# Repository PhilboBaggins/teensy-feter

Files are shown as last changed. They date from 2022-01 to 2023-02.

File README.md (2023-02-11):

# Teensy FETer

A small board with 10 power outputs driven from FETs configured as high side switches and controlled by a Teensy LC. This board was mainly created for experimenting with solenoids.

| Photo of board using external power |  Photo of board using USB power |
| --- |  --- |
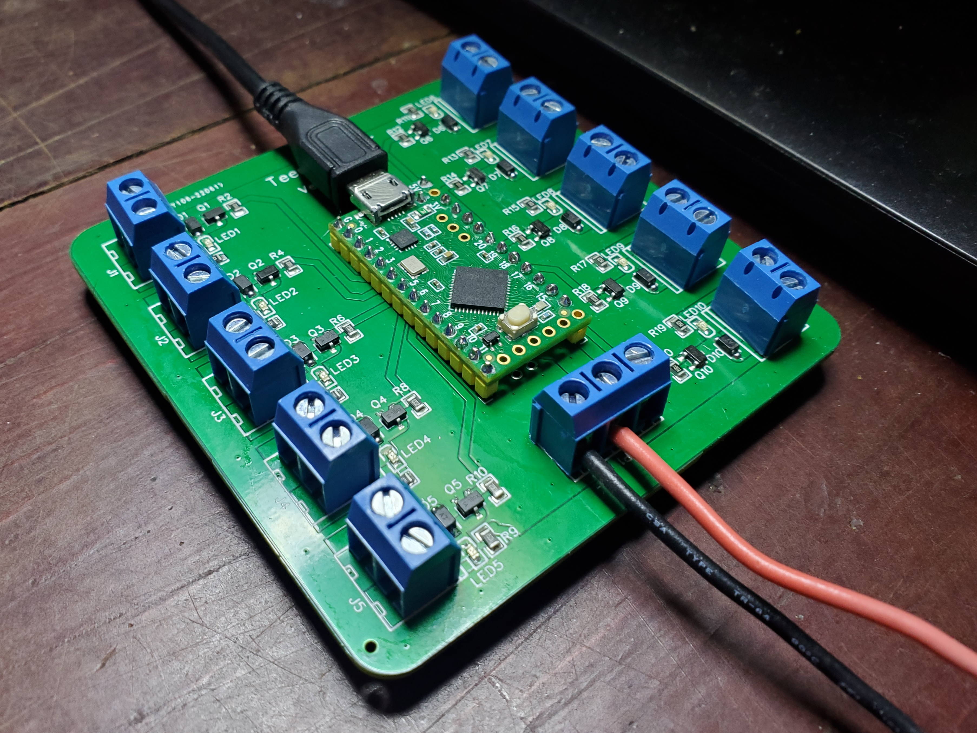
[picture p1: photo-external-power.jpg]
Photo of board using external power
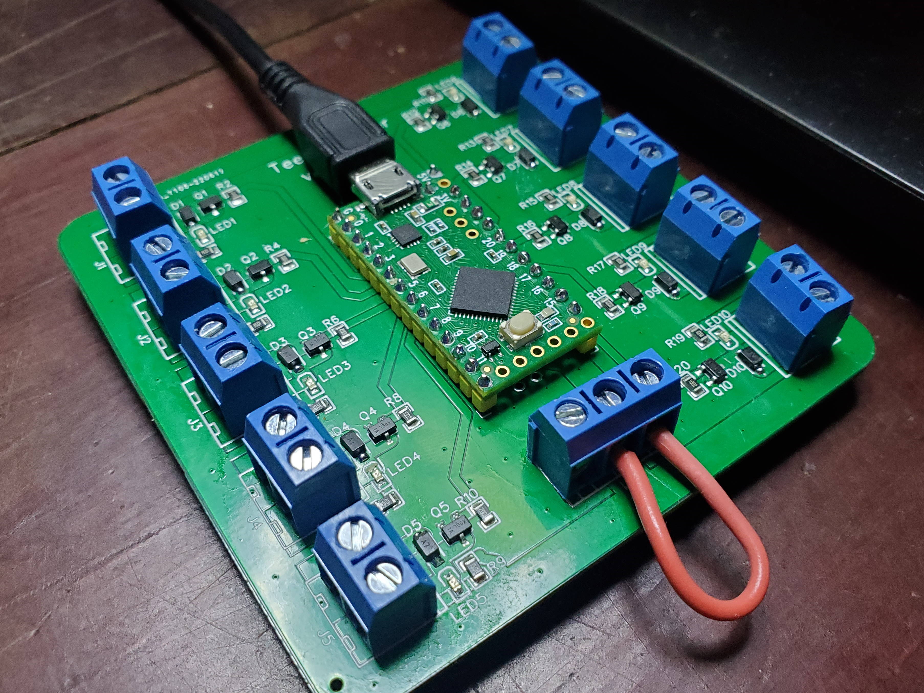
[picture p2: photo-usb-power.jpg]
Photo of board using USB power
|  |  |

## Output pins

Each of the 10 outputs is controlled by a single Teensy pin:

| Output | Teensy pin |
| --- | --- |
| OUT1 | 2 |
| OUT2 | 3 |
| OUT3 | 4 |
| OUT4 | 5 |
| OUT5 | 6 |
| OUT6 | 23 |
| OUT7 | 22 |
| OUT8 | 21 |
| OUT9 | 20 |
| OUT10  | 19 |

## Usage notes

The "external power" pin (centre of the 3 pin screw terminal) is connected to the first pin of each of the output connectors (2 pin screw terminals). These aren't clearly labelled on the v1.0 boards, so if you're unsure look at the bottom of the board and follow the thick copper trace going around the outside of the board.

Whatever power is connected to the "external power" pin will supply power to whatever load you've connected to the output connectors (e.g. a solenoid). The LEDs on the board are also driven from the "external power".

There are two principle ways of using this board, which are shown in the photos above and described in more detail in the paragraphs below.

### Configuration 1 - External power supply

This board can be powered from an external power by connecting it pins 1 and 2 of the 3 pin screw terminal as shown in the photo above (the one on the left). Ground from the external supply should be connected to pin 1 and power to pin 2.

In this configuration the external power supply is connected to the "external power" pin and will, as described above, power the loads connected to the output connectors.

By default, the "external power" is not connected to the Teensy's power rails, which means:

* the Teensy will not be powered from the external power supply and must instead be powered from another source (e.g. from USB)
* you can connect a higher voltage to the "external power" pin than the Teensy allows (e.g. 12 volts)

However, the "external power" pin and the Teensy's VUSB pin can be linked together by linking pins 2 and 3 on the 3 pin screw terminal (as shown in the right side photo above). If you do this while providing power to the "external power" pin from an external power supply then the Teensy AND the output connectors will be powered from the external power supply - you should only do this if suppling a voltage the Teensy allows on it's VUSB pin (e.g. 5 volts) and no other power is connected to the Teensy (e.g. don't have USB power connected at the same time).

### Configuration 2 - USB power

By linking pins 2 and 3 on the 3 pin screw terminal (as shown in the right side photo above) and not providing any external power supply, the outputs and the Teensy can be powered from the Teensy's USB power.

This is useful for testing and for when you only need to control low power devices with the boards outputs (e.g. small 5V solenoids). Be aware that USB power doesn't usually supply much current (generally limited to 1 amp) and it a computer is supplying the USB power it may cut you off if you try to draw more than it allows.

## TODO

* [ ] TODO: Add silkscreen labels on 2 pin screw terminals
* [ ] TODO: Add silkscreen labels on 3 pin screw terminals
* [ ] TODO: More example code?

## Licence

Copyright © 2021, 2022, 2023 Phil Baldwin

This work is licensed under a Creative Commons Attribution-ShareAlike 4.0 International License.

You should have received a copy of the license along with this work. If not, see <http://creativecommons.org/licenses/by-sa/4.0/>.

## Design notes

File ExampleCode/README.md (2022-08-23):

Example code
============

| Example  | Framework | Description |
| --- | --- | --- |
| Example1 | Arduino/TeensyDuino | Basic example. Shows which pins to use and how to configure them. Then it turns on output 0 and blinks the other 9 on and off |
| Example2 | Arduino/TeensyDuino | Same as Example1 but uses a custom class to control the board's outputs |
| Example3 | Arduino/TeensyDuino | Uses the class from Example2 to toggle the outputs when asked to do so by receiving data from the USB serial port |

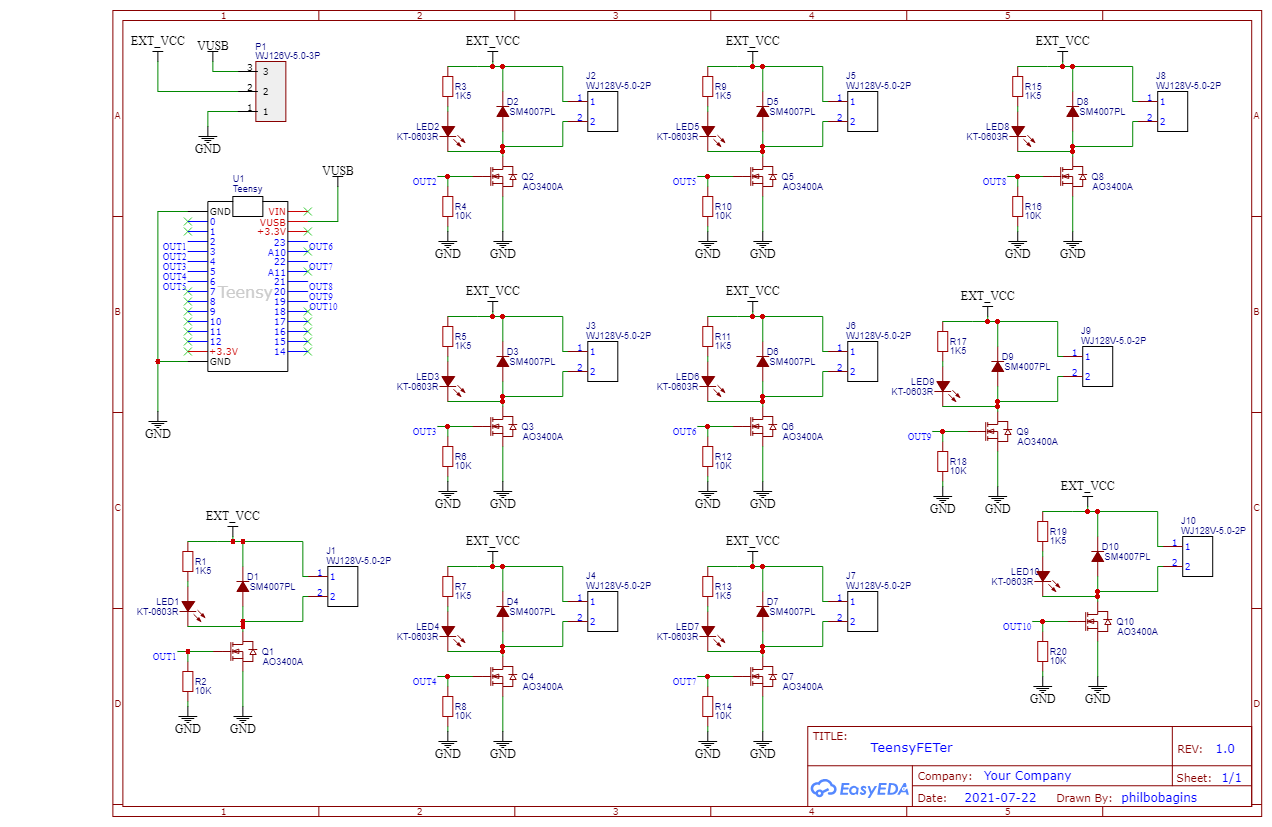
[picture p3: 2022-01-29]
Exports-v1.0/Schematic.png

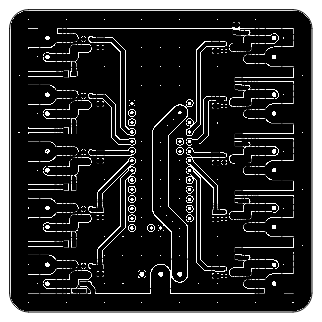
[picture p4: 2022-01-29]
Exports-v1.0/PCB.png

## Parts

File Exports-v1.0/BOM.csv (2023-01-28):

ID | Name | Designator | Footprint | Quantity | Manufacturer Part | Manufacturer | Supplier | Supplier Part | Price
1 | AO3400A | Q1,Q2,Q3,Q4,Q5,Q6,Q7,Q8,Q9,Q10 | SOT-23-3_L2.9-W1.6-P1.90-LS2.8-BR | 10 | AO3400A | AOS | LCSC | C20917 | 0.162
2 | WJ128V-5.0-2P | J1,J2,J3,J4,J5,J6,J7,J8,J9,J10 | CONN-TH_2P-P5.00_WJ128V-5.0-2P | 10 | WJ128V-5.0-2P | ReliaPro | LCSC | C8269 | 0.155
3 | Teensy | U1 | TEENSY LC/3.0/3.1/3.2 | 1
4 | KT-0603R | LED1,LED2,LED3,LED4,LED5,LED6,LED7,LED8,LED9,LED10 | LED0603-R-RD | 10 | KT-0603R | KENTO | LCSC | C2286
5 | SM4007PL | D1,D2,D3,D4,D5,D6,D7,D8,D9,D10 | SOD-123F_L2.8-W1.8-LS3.7-RD | 10 | SM4007PL | MDD | LCSC | C64898 | 0.008
6 | 1K5 | R3,R5,R7,R9,R11,R13,R15,R17,R19,R1 | R0805 | 10 | 0805W8F1501T5E | UniOhm | LCSC | C4310
7 | 10K | R4,R6,R8,R10,R12,R14,R16,R18,R20,R2 | R0805 | 10 | 0805W8F1002T5E | UniOhm | LCSC | C17414
8 | WJ126V-5.0-3P | P1 | CONN-TH_3P-P5.00_WJ126V-5.0-3P | 1 | WJ126V-5.0-3P | ReliaPro | LCSC | C8401 | 0.111

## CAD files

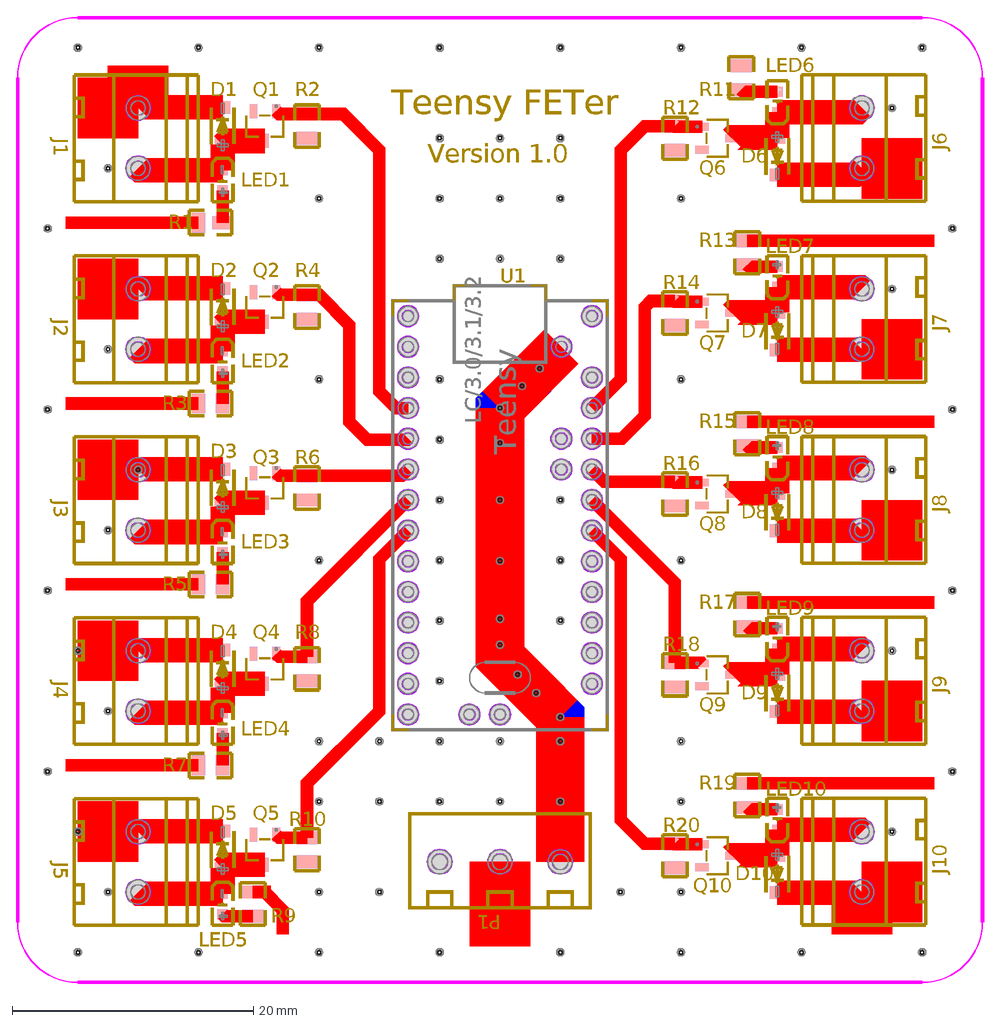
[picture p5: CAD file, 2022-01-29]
Exports-v1.0/PCB.dxf
Teensy FETer
Version 1.0
Q1
Q2
Q3
Q4
Q5
Q6
Q7
Q8
Q9
Q10
J1
U1
Teensy
LC/3.0/3.1/3.2
LED1
D1
D2
D3
D4
D5
D6
D7
D8
D9
D10
J2
J3
J4
J5
J6
J7
J8
J9
J10
LED2
LED3
LED4
LED5
LED6
LED7
LED8
LED9
LED10
R3
R4
R5
R6
R7
R8
R9
R10
R11
R12
R13
R14
R15
R16
R17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

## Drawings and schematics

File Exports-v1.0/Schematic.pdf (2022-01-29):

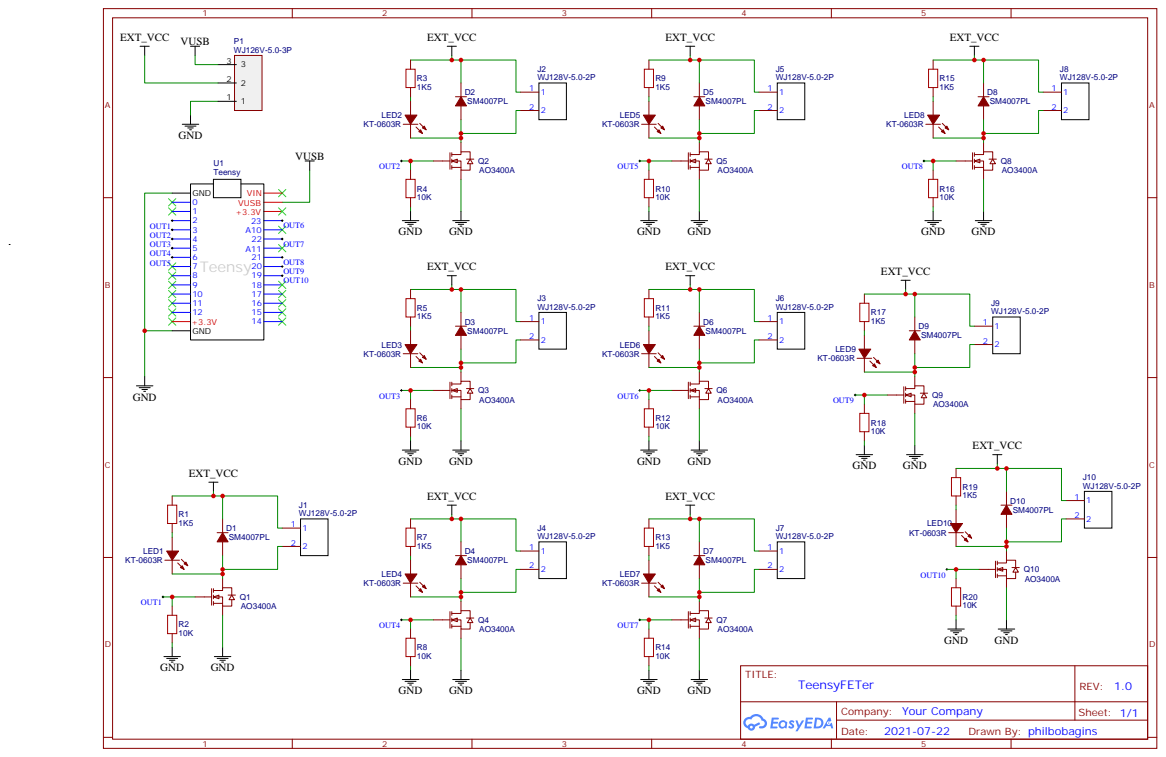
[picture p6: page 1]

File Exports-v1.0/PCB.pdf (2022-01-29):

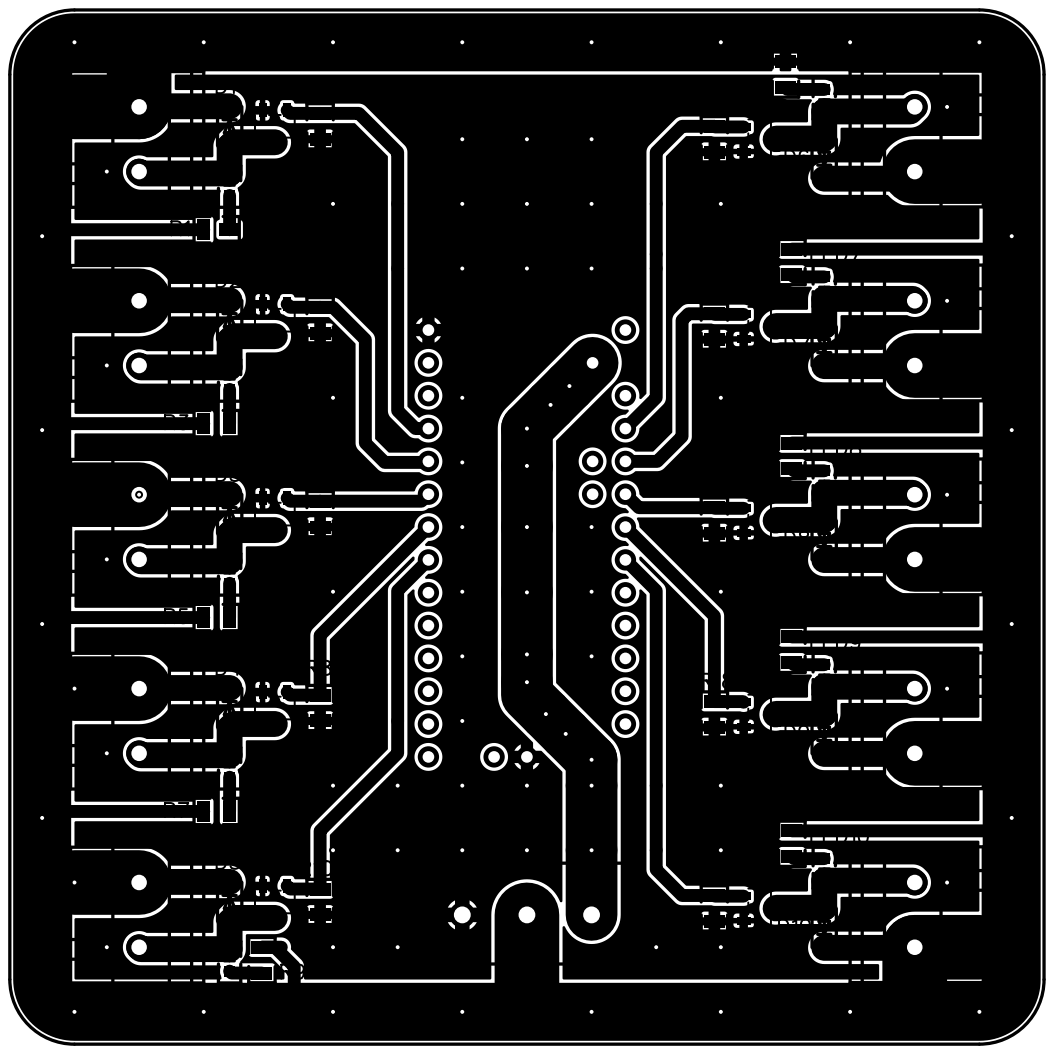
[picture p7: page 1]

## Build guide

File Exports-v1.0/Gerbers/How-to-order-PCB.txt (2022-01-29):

How to Order PCB

Please refer to:
https://docs.easyeda.com/en/PCB/Order-PCB

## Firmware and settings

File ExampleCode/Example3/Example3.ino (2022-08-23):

#include "TeensyFeterControl.h"

TeensyFeterControl tFets;

void setup()
{
    Serial.begin(115200);
    tFets.begin();
    tFets.allOff();
}
 
void loop()
{
    if (Serial.available())
    {
        switch(Serial.read())
        {
            case '0': tFets.outputToggle(0); break;
            case '1': tFets.outputToggle(1); break;
            case '2': tFets.outputToggle(2); break;
            case '3': tFets.outputToggle(3); break;
            case '4': tFets.outputToggle(4); break;
            case '5': tFets.outputToggle(5); break;
            case '6': tFets.outputToggle(6); break;
            case '7': tFets.outputToggle(7); break;
            case '8': tFets.outputToggle(8); break;
            case '9': tFets.outputToggle(9); break;
            default: /* Ignore anything else */ break;
        }
    }
}

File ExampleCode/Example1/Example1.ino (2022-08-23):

const int PIN_NUMBERS[]
{
    2,
    3,
    4,
    5,
    6,
    23,
    22,
    21,
    20,
    19,
};
const int NUM_OUTPUTS = sizeof(PIN_NUMBERS) / sizeof(int);

void setup()
{
    // Configure all outputs and turn them off
    for (int pinIdx = 0; pinIdx < NUM_OUTPUTS; pinIdx++)
    {
        pinMode(PIN_NUMBERS[pinIdx], OUTPUT);
        digitalWrite(PIN_NUMBERS[pinIdx], LOW);
    }
}

void loop()
{
    digitalWrite(PIN_NUMBERS[0], HIGH); // Turn on first output

    // Blink all other outputs on and off
    for (int pinIdx = 1; pinIdx < NUM_OUTPUTS; pinIdx++)
    {
        int pinNum = PIN_NUMBERS[pinIdx];
        digitalWrite(pinNum, !digitalRead(pinNum));
    }

    delay(300);
}

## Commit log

2022-01-29 Assign LCSC part numbers to resistors
2022-01-29 Add v1.0 exports
    [BOM.csv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]
2023-01-28 Reencode BOM.csv to UTF-8
    [BOM.csv]
2023-01-28 Convert BOM from tab separated to comma separated
    [BOM.csv]
